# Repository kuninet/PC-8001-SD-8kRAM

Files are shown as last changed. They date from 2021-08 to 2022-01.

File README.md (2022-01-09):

# PC-8001 8kB SRAM/MicroSD/RTCボード

## 概要

* PC-8001 拡張CPUバスにつながる8kB SRAM、MicroSD、RTC搭載ボードです。
* SD-DOSが動きます。

## 部品表
* 部品表は以下のCSVファイルを参照ください。
  * [部品表](KiCAD/PC8001-SD-8kRAM.csv)

## 回路図
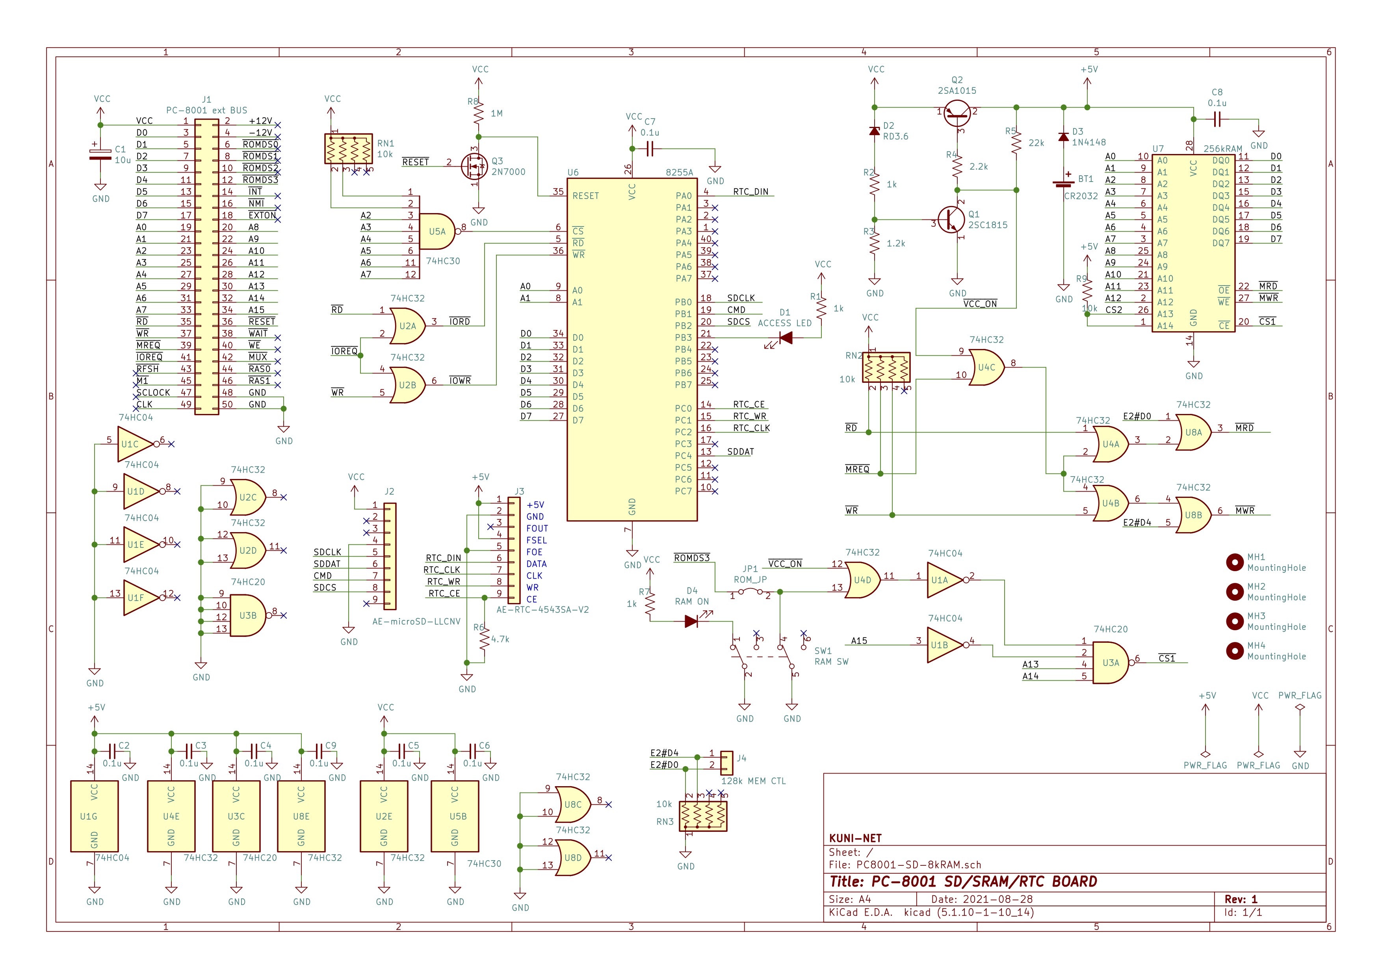
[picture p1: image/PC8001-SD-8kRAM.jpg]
回路図


## 稼働させる際の注意 
### ★電圧調整の際はテスタで計測しながら、トリマは慎重にまわしてください。ちょっと動かすだけで6Vなどの電圧が出ます。PC-8001のメインボードのICが壊れる可能性があります。

* PC-8001の電源電圧が下がっている場合があります。外部基板としてつなげた本基板にきている電圧が4.5Vなどになっていると安定しません。PC-8001の電源ユニット内の調整トリマを回して5V程度出るようにしてください。
* [2022/1/8追記] 回路図のツェナーダイオードの定格をRD4.2 → RD3.6としました。本体電圧を調整することなく安定すると思われます。

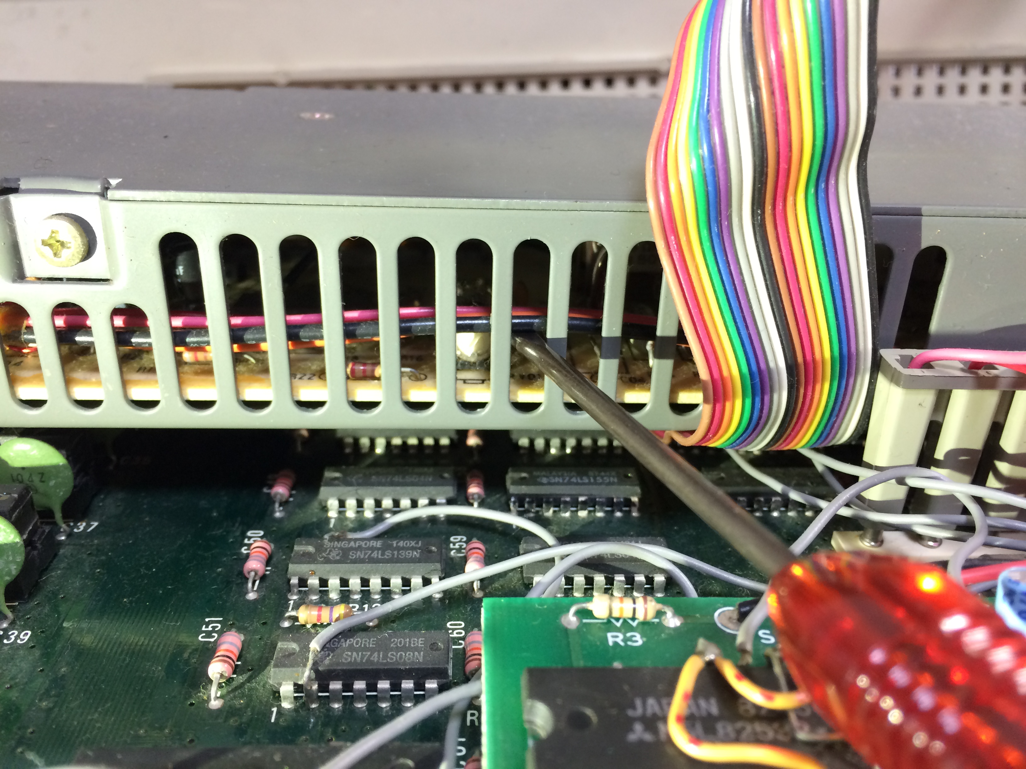
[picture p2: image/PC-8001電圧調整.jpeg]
電圧調整


## 参考

* SD-DOS
  * https://github.com/chiqlappe/SD-DOS
* PC-8001 MicroSDボード
  * https://github.com/chiqlappe/sdd
* PC-8001 8k SRAMボード
  * https://github.com/chiqlappe/ram8k
* PC8001 RTCドライバー
  * https://github.com/chiqlappe/rtc

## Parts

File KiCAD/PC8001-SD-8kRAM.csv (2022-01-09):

BT1 | CR2032 | Battery_local:BatteryHolder_20mmwide | ~
C1 | 10u | Capacitor_THT:CP_Radial_D5.0mm_P2.50mm | ~
C2 | 0.1u | Capacitor_THT:C_Disc_D3.0mm_W1.6mm_P2.50mm | ~
C3 | 0.1u | Capacitor_THT:C_Disc_D3.0mm_W1.6mm_P2.50mm | ~
C4 | 0.1u | Capacitor_THT:C_Disc_D3.0mm_W1.6mm_P2.50mm | ~
C5 | 0.1u | Capacitor_THT:C_Disc_D3.0mm_W1.6mm_P2.50mm | ~
C6 | 0.1u | Capacitor_THT:C_Disc_D3.0mm_W1.6mm_P2.50mm | ~
C7 | 0.1u | Capacitor_THT:C_Disc_D3.0mm_W1.6mm_P2.50mm | ~
C8 | 0.1u | Capacitor_THT:C_Disc_D3.0mm_W1.6mm_P2.50mm | ~
D1 | ACCESS LED | LED_THT:LED_D3.0mm | ~
D2 | RD3.6 | Diode_THT:D_DO-34_SOD68_P7.62mm_Horizontal | ~
D3 | 1N4148 | Diode_THT:D_DO-34_SOD68_P7.62mm_Horizontal | ~
D4 | RAM ON | LED_THT:LED_D3.0mm | ~
J1 | PC-8001 ext BUS | Connector_PinHeader_2.54mm:PinHeader_2x25_P2.54mm_Horizontal | ~
J2 | AE-microSD-LLCNV | AE:AE-microSD-LLCNV | ~
J3 | AE-RTC-4543SA-V2 | Connector_PinHeader_2.54mm:PinHeader_1x09_P2.54mm_Vertical | ~
MH1 | MountingHole | MountingHole:MountingHole_3.2mm_M3 | ~
MH2 | MountingHole | MountingHole:MountingHole_3.2mm_M3 | ~
MH3 | MountingHole | MountingHole:MountingHole_3.2mm_M3 | ~
MH4 | MountingHole | MountingHole:MountingHole_3.2mm_M3 | ~
Q1 | 2SC1815 | Package_TO_SOT_THT:TO-92_Inline_Wide | https://media.digikey.com/pdf/Data%20Sheets/Toshiba%20PDFs/2SC1815.pdf
Q2 | 2SA1015 | Package_TO_SOT_THT:TO-92_Inline_Wide | http://www.datasheetcatalog.org/datasheet/toshiba/905.pdf
Q3 | 2N7000 | Package_TO_SOT_THT:TO-92_Inline_Wide | https://www.fairchildsemi.com/datasheets/2N/2N7000.pdf
R1 | 1k | Resistor_THT:R_Axial_DIN0207_L6.3mm_D2.5mm_P10.16mm_Horizontal | ~
R2 | 1k | Resistor_THT:R_Axial_DIN0207_L6.3mm_D2.5mm_P10.16mm_Horizontal | ~
R3 | 1.2k | Resistor_THT:R_Axial_DIN0207_L6.3mm_D2.5mm_P10.16mm_Horizontal | ~
R4 | 2.2k | Resistor_THT:R_Axial_DIN0207_L6.3mm_D2.5mm_P10.16mm_Horizontal | ~
R5 | 22k | Resistor_THT:R_Axial_DIN0207_L6.3mm_D2.5mm_P10.16mm_Horizontal | ~
R6 | 4.7k | Resistor_THT:R_Axial_DIN0207_L6.3mm_D2.5mm_P10.16mm_Horizontal | ~
R7 | 1k | Resistor_THT:R_Axial_DIN0207_L6.3mm_D2.5mm_P10.16mm_Horizontal | ~
R8 | 1M | Resistor_THT:R_Axial_DIN0207_L6.3mm_D2.5mm_P10.16mm_Horizontal | ~
R9 | 10k | Resistor_THT:R_Axial_DIN0207_L6.3mm_D2.5mm_P10.16mm_Horizontal | ~
Reference | Value | Footprint | Datasheet
RN1 | 10k | Resistor_THT:R_Array_SIP5 | http://www.vishay.com/docs/31509/csc.pdf
RN2 | 10k | Resistor_THT:R_Array_SIP5 | http://www.vishay.com/docs/31509/csc.pdf
SW1 | RAM SW | AE:SS-22SDP2 | ~
U1 | 74HC04 | Package_DIP:DIP-14_W7.62mm_Socket_LongPads | http://www.ti.com/lit/gpn/sn74LS04
U2 | 74HC32 | Package_DIP:DIP-14_W7.62mm_Socket_LongPads | http://www.ti.com/lit/gpn/sn74LS32
U3 | 74HC20 | Package_DIP:DIP-14_W7.62mm_Socket_LongPads | http://www.ti.com/lit/gpn/sn74LS20
U4 | 74HC32 | Package_DIP:DIP-14_W7.62mm_Socket_LongPads | http://www.ti.com/lit/gpn/sn74LS32
U5 | 74HC30 | Package_DIP:DIP-14_W7.62mm_Socket_LongPads | http://www.ti.com/lit/gpn/sn74LS30
U6 | 8255A | Package_DIP:DIP-40_W15.24mm_Socket_LongPads | http://aturing.umcs.maine.edu/~meadow/courses/cos335/Intel8255A.pdf
U7 | 256kRAM | Package_SO:SOIC-28W_7.5x17.9mm_P1.27mm | http://www.cypress.com/file/136521/download

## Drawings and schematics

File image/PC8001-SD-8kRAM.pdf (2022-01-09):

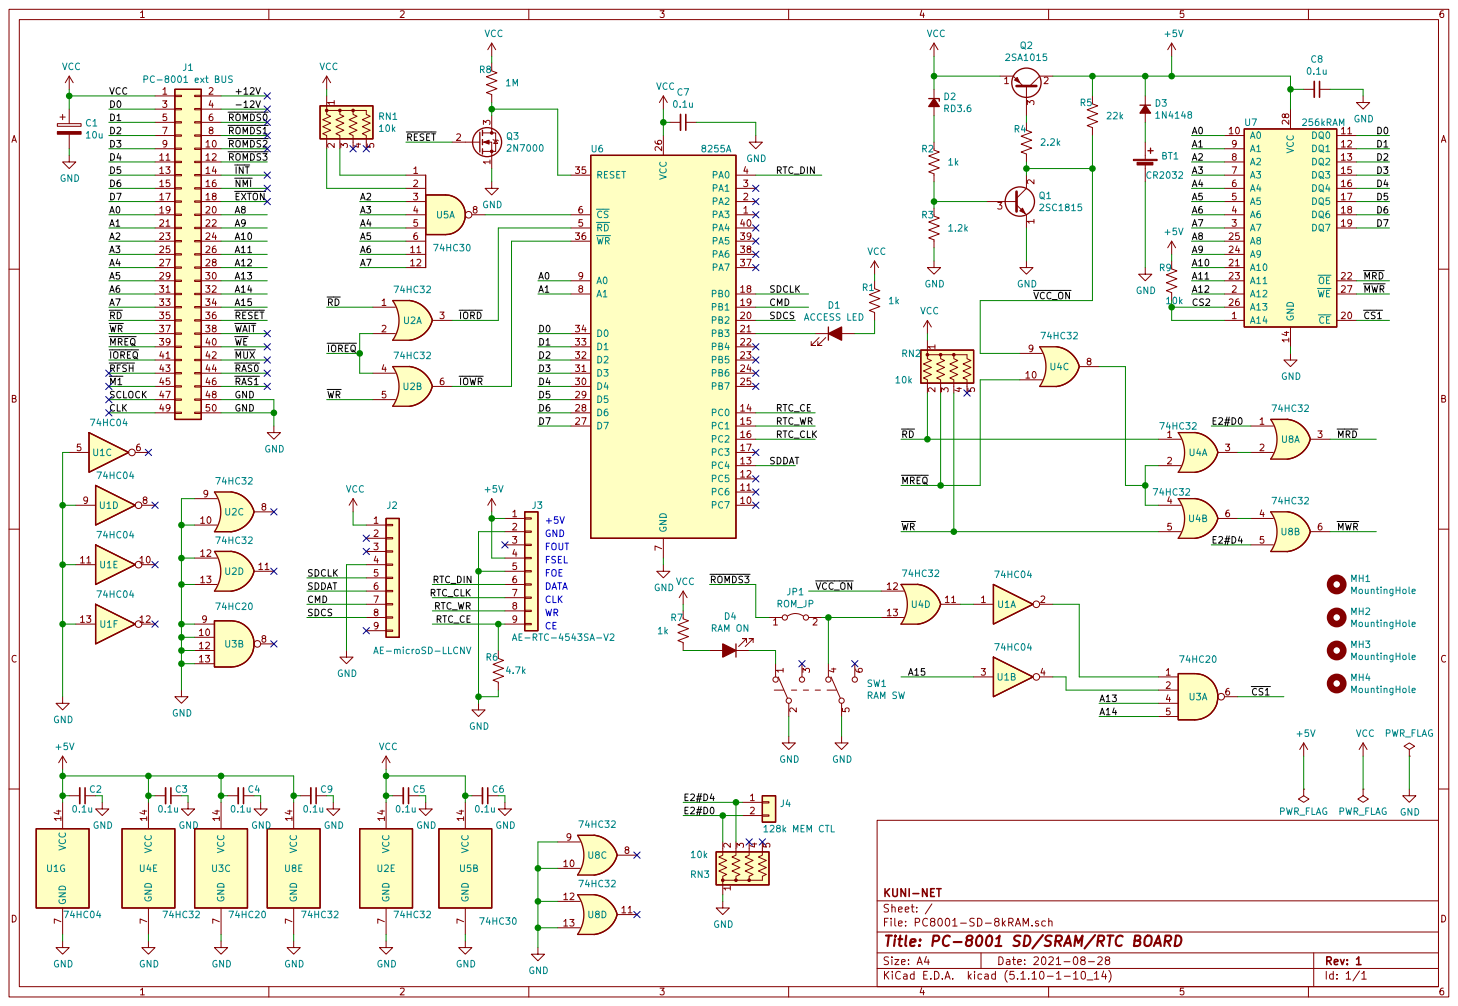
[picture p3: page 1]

7 A1 8 A0 9 U6 8255A MH4 MountingHole MH3 MountingHole MH2 MountingHole MH1 MountingHole PWR_FLAG

File: PC8001-SD-8kRAM.sch Sheet: / KUNI-NET

Id: 1/1 Title: PC-8001 SD/SRAM/RTC BOARD

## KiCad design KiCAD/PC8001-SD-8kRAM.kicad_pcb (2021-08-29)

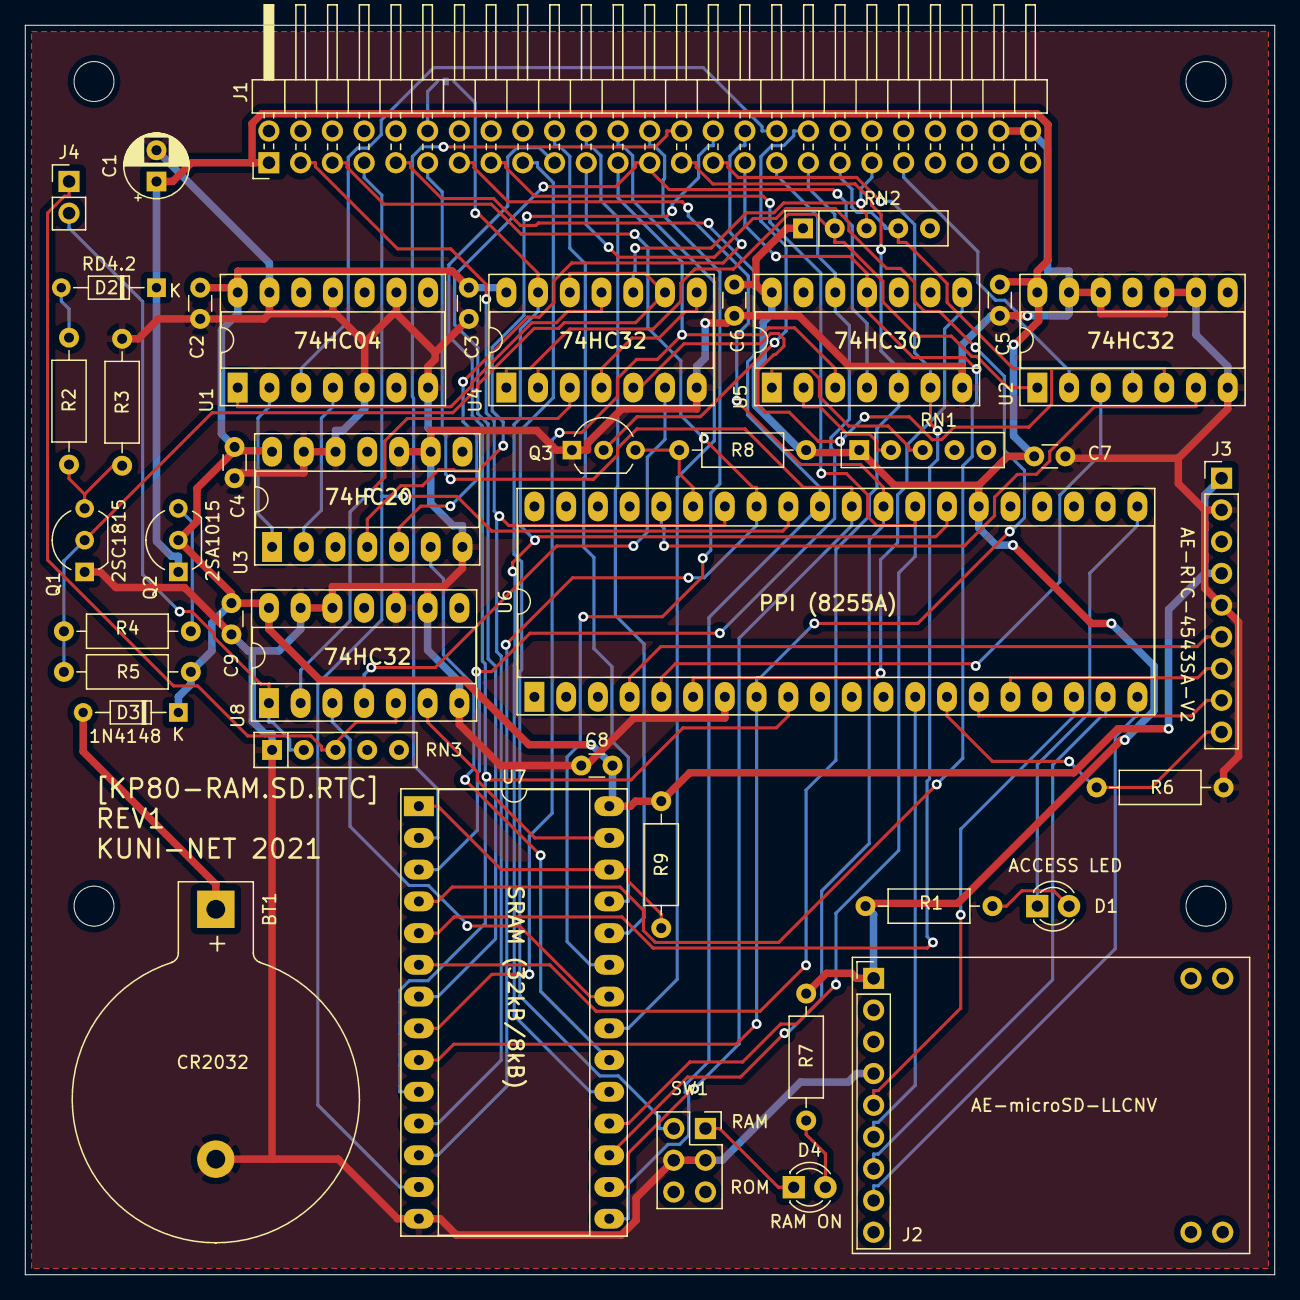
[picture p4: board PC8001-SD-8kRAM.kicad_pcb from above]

Board: 2 copper layers, 100.0 x 100.0 mm, 47 parts (1 on the bottom side), 69 nets.

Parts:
BT1: CR2032; BatteryHolder_20mmwide
C1: 10u; CP_Radial_D5.0mm_P2.50mm
C2, C3, C4, C5, C6, C7, C8, C9: 0.1u; C_Disc_D3.0mm_W1.6mm_P2.50mm
D1: ACCESS LED; LED_D3.0mm
D2: RD4.2; D_DO-34_SOD68_P7.62mm_Horizontal
D3: 1N4148; D_DO-34_SOD68_P7.62mm_Horizontal
D4: RAM ON; LED_D3.0mm
J1: PC-8001 ext BUS; PinHeader_2x25_P2.54mm_Horizontal
J2: AE-microSD-LLCNV
J3: AE-RTC-4543SA-V2; PinHeader_1x09_P2.54mm_Vertical
J4: 128k MEM CTL; PinHeader_1x02_P2.54mm_Vertical
JP1: ROM_JP; SolderJumper-2_P1.3mm_Bridged_RoundedPad1.0x1.5mm
MH1, MH2, MH3, MH4: MountingHole; MountingHole_3.2mm_M3
Q1: 2SC1815; TO-92_Inline_Wide
Q2: 2SA1015; TO-92_Inline_Wide
Q3: 2N7000; TO-92_Inline_Wide
R1, R2, R7: 1k; R_Axial_DIN0207_L6.3mm_D2.5mm_P10.16mm_Horizontal
R3: 1.2k; R_Axial_DIN0207_L6.3mm_D2.5mm_P10.16mm_Horizontal
R4: 2.2k; R_Axial_DIN0207_L6.3mm_D2.5mm_P10.16mm_Horizontal
R5: 22k; R_Axial_DIN0207_L6.3mm_D2.5mm_P10.16mm_Horizontal
R6: 4.7k; R_Axial_DIN0207_L6.3mm_D2.5mm_P10.16mm_Horizontal
R8: 1M; R_Axial_DIN0207_L6.3mm_D2.5mm_P10.16mm_Horizontal
R9: 10k; R_Axial_DIN0207_L6.3mm_D2.5mm_P10.16mm_Horizontal
RN1, RN2, RN3: 10k; R_Array_SIP5
SW1: RAM SW; SS-22SDP2
U1: 74HC04; DIP-14_W7.62mm_Socket_LongPads
U2, U4, U8: 74HC32; DIP-14_W7.62mm_Socket_LongPads
U3: 74HC20; DIP-14_W7.62mm_Socket_LongPads
U5: 74HC30; DIP-14_W7.62mm_Socket_LongPads
U6: 8255A; DIP-40_W15.24mm_Socket_LongPads
U7: 256kRAM; DIP-28_W15.24mm_Socket_LongPads

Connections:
+5V: C2.2, C3.2, C4.2, C8.2, C9.2, D3.1, J3.1, J3.4, Q2.2, R5.1, R9.1, U1.14, U3.14, U4.14, U7.28, U8.14
/A0: J1.19, U6.9, U7.10
/A1: J1.21, U6.8, U7.9
/A2: J1.23, U5.3, U7.8
/A3: J1.25, U5.4, U7.7
/A4: J1.27, U5.5, U7.6
/A5: J1.29, U5.6, U7.5
/A6: J1.31, U5.11, U7.4
/A7: J1.33, U5.12, U7.3
/A8: J1.20, U7.25
/A9: J1.22, U7.24
/A10: J1.24, U7.21
/A11: J1.26, U7.23
/A12: J1.28, U7.2
/A13: J1.30, U3.4
/A14: J1.32, U3.5
/A15: J1.34, U1.3
/CMD: J2.7, U6.19
/CS2: R9.2, U7.1, U7.26
/D0: J1.3, U6.34, U7.11
/D1: J1.5, U6.33, U7.12
/D2: J1.7, U6.32, U7.13
/D3: J1.9, U6.31, U7.15
/D4: J1.11, U6.30, U7.16
/D5: J1.13, U6.29, U7.17
/D6: J1.15, U6.28, U7.18
/D7: J1.17, U6.27, U7.19
/E2#D0: J4.2, RN3.2, U8.1
/E2#D4: J4.1, RN3.3, U8.5
/RTC_CE: J3.9, R6.1, U6.14
/RTC_CLK: J3.7, U6.16
/RTC_DIN: J3.6, U6.4
/RTC_WR: J3.8, U6.15
/SDCLK: J2.5, U6.18
/SDCS: J2.8, U6.20
/SDDAT: J2.6, U6.13
/~CS1: U3.6, U7.20
/~IORD: U2.3, U6.5
/~IOREQ: J1.41, U2.2, U2.4
/~IOWR: U2.6, U6.36
/~MRD: U7.22, U8.3
/~MREQ: J1.39, RN2.3, U4.10
/~MWR: U7.27, U8.6
/~RD: J1.35, RN2.2, U2.1, U4.1
/~RESET: J1.36, Q3.2
/~ROMDS3: J1.12, JP1.1
/~VCC_ON: Q1.2, R4.2, R5.2, U4.9, U4.12
/~WR: J1.37, RN2.4, U2.5, U4.5
GND: BT1.2, C1.2, C2.1, C3.1, C4.1, C5.1, C6.1, C7.1, C8.1, C9.1, J1.48, J1.50, J2.4, J3.2, J3.5, Q1.1, Q3.1, R3.2, R6.2, RN3.1, SW1.2, SW1.5, U1.5, U1.7, U1.9, U1.11, U1.13, U2.7, U2.9, U2.10, U2.12, U2.13, U3.7, U3.9, U3.10, U3.12, U3.13, U4.7, U5.7, U6.7, U7.14, U8.7, U8.9, U8.10, U8.12, U8.13
unnamed: BT1.1, D3.2
unnamed: D1.1, U6.21
unnamed: D1.2, R1.2
unnamed: D2.2, R2.1
unnamed: D4.1, SW1.1
unnamed: D4.2, R7.2
unnamed: JP1.2, SW1.4, U4.13
unnamed: Q1.3, R2.2, R3.1
unnamed: Q2.3, R4.1
unnamed: Q3.3, R8.2, U6.35
unnamed: RN1.2, U5.2
unnamed: RN1.3, U5.1
unnamed: U1.1, U4.11
unnamed: U1.2, U3.1
unnamed: U1.4, U3.2
unnamed: U4.2, U4.4, U4.8
unnamed: U4.3, U8.2
unnamed: U4.6, U8.4
unnamed: U5.8, U6.6
VCC: C1.1, C5.2, C6.2, C7.2, D2.1, J1.1, J2.1, Q2.1, R1.1, R7.1, R8.1, RN1.1, RN2.1, U2.14, U5.14, U6.26

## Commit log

2021-08-29 README追記
2021-08-29 ROMDS3切り離し用ジャンパパッド追加
    [PC8001-SD-8kRAM.GBL, PC8001-SD-8kRAM.GBO, PC8001-SD-8kRAM.GBP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]
2021-12-08 READMEの詳細化。回路図イメージ追加
2022-01-09 回路図のツェナーダイオード定格を変更 RD4.2→RD3.6
    [PC8001-SD-8kRAM.csv, PC8001-SD-8kRAM.sch]
